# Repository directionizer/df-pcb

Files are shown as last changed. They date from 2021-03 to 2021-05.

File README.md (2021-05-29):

# df-pcb

Directionizer is a student project by Mason Ahner, Jared Beller, and John Fiorini for the spring 2021 session of ECE 2804 at Virginia Tech. The "directionizer" is a handheld device for locating a 1 kHz audio beacon. This repository contains KiCad schematics and PCBs for the directionizer hardware.

## Structure

The original design made during prototyping can be found in [schematic](schematic/). This was broken into three individual boards, which are stacked to form the final device. From bottom to top, the boards are [processing](processing/), [audio](audio/), and [display](display/). Each board's schematic and layout is in it's respective folder. For manufacturing, the three boards were combined into a panel. The final panel layout can be seen in the [panel](panel/) folder. Files sent to the board house, including gerbers, a bom, and smt placement, are in the [production](production/) folder.

## Licensing

Copyright (C) 2021  Mason Ahner, Jared Beller, and John Fiorini

This program is released under the [GNU General Public License, Version 3](https://www.gnu.org/licenses/gpl-3.0.txt) or later. See [LICENSE](LICENSE) for more information.

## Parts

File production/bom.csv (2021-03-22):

Comment | Designator | Footprint | LCSC Part No.
22pF | C1,C3,C9,C10,C15,C21,C27 | 0603 | C1653
4.7nF | C16,C18,C22,C24,C28,C30 | 0603 | C53987
10nF | C2 | 0603 | C57112
100nF | C4,C5,C6,C7,C8,C11,C12,C33,C34 | 0603 | C14663
2.2uF | C13,C17,C19,C20,C23,C25,C26,C29,C31,C32 | 3216 | C179115
10uF | C14 | 0805 | C15850
10uH | L1 | 0805 | C1046
330R | R40,R44,R48 | 0603 | C23138
390R | R37,R38,R39,R41,R42,R43,R45,R46,R47,R49,R50,R51 | 0603 | C23151
680R | R36 | 0603 | C23228
2.7k | R15,R24,R33 | 0603 | C13167
3k | R17,R26,R35 | 0603 | C4211
5.1k | R1,R2 | 0603 | C23186
5.6k | R10,R19,R28 | 0603 | C23189
8.2k | R4 | 0603 | C25981
10k | R6 | 1206 | C17902
12k | R3,R12,R21,R30 | 0603 | C22790
51k | R14,R23,R32 | 0603 | C23196
100k | R7,R8,R16,R25,R34 | 0603 | C25803
220k | R13,R22,R31 | 0603 | C22961
430k | R11,R20,R29 | 0603 | C25969
1M | R5,R9,R18,R27 | 0603 | C22935
12MHz | Y1 | 3225 | C9002
16MHz | Y2 | 3225 | C13738
Schottky | D1,D2,D3 | SOD-123 | C8598
Push Button | SW1 | SPST_SKQG | C318884
CH340G | U1 | SOIC-16 | C14267
ATmega328P-AU | U2 | TQFP-32 | C14877
LM324DT | U3,U4 | SOIC-14 | C71035
74HC238 | U5,U6 | SOIC-16 | C5620
TYPE-C-31-M-12 | J4 | TYPE-C-31_L8.94_W7.3 | C165948

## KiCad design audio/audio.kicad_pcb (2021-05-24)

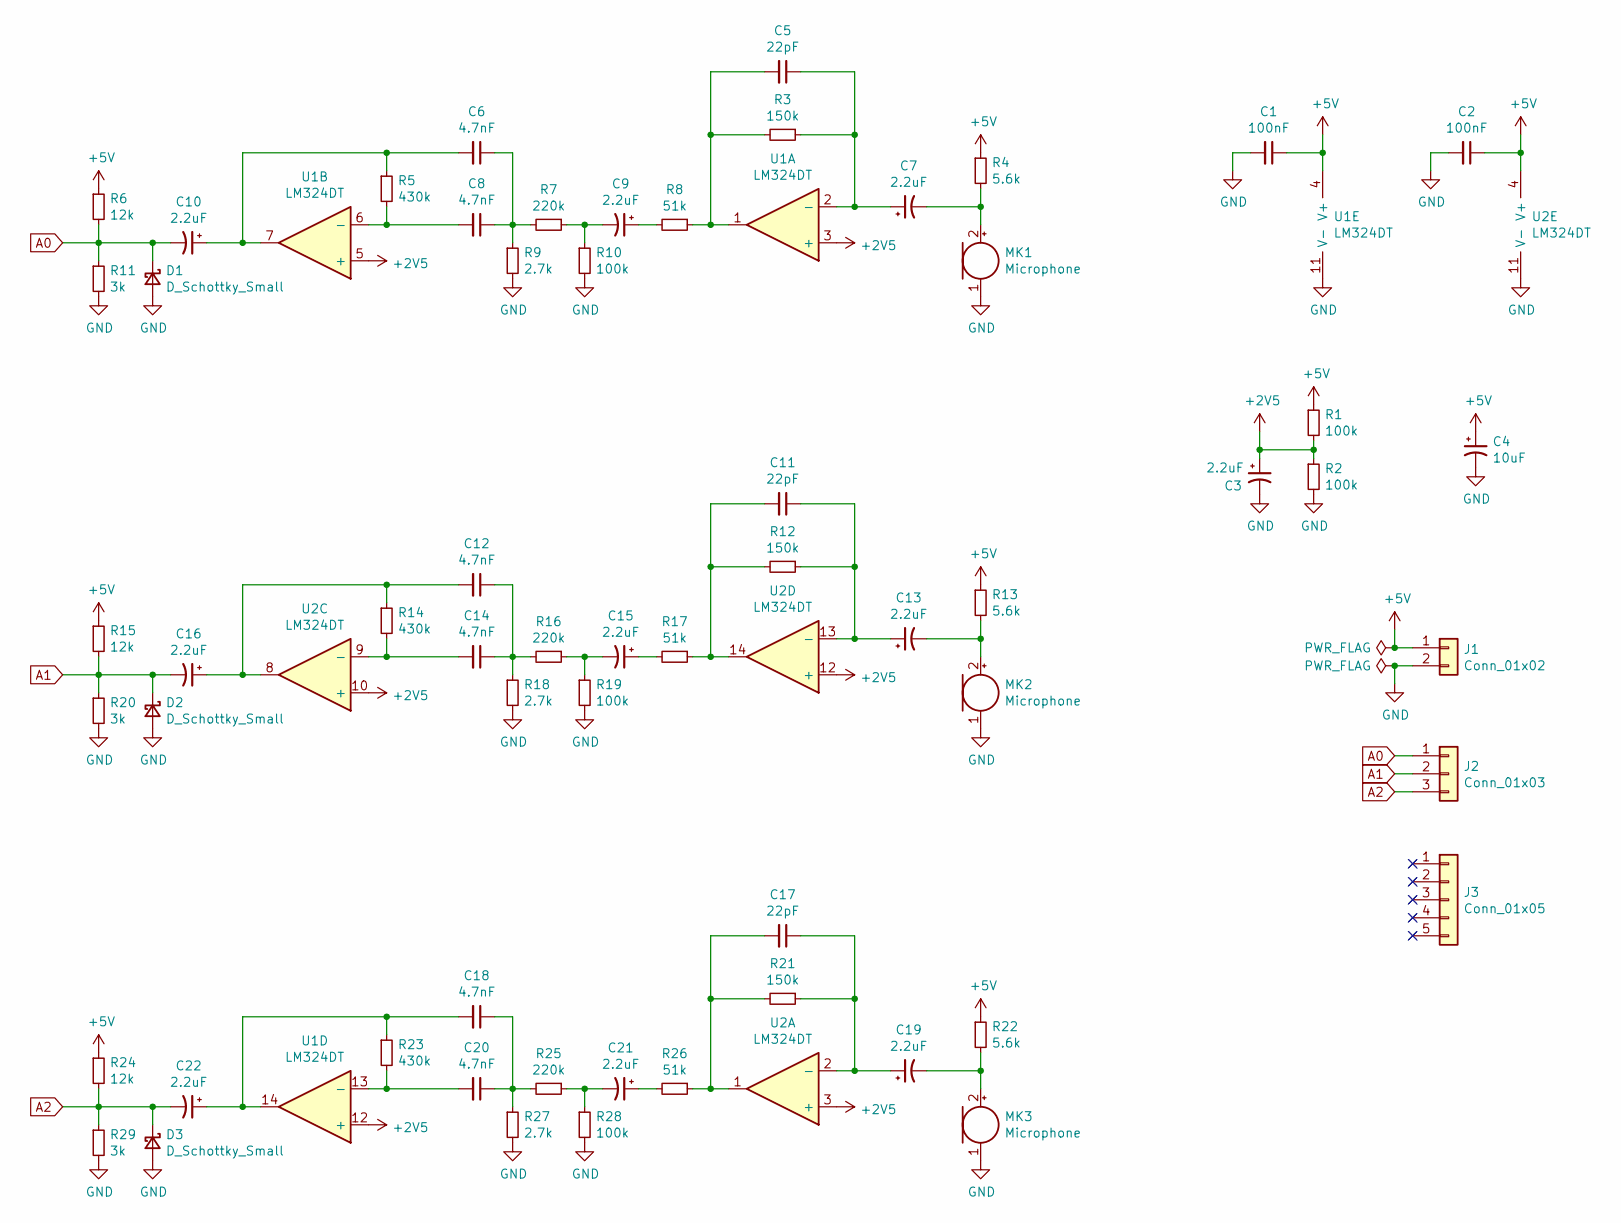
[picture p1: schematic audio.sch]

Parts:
C1, C2: 100nF; C_0603_1608Metric
C3, C7, C9, C10, C13, C15, C16, C19, C21, C22: 2.2uF; CP_EIA-3216-18_Kemet-A
C4: 10uF; CP_EIA-3216-18_Kemet-A
C5, C11, C17: 22pF; C_0603_1608Metric
C6, C8, C12, C14, C18, C20: 4.7nF; C_0603_1608Metric
D1, D2, D3: D_Schottky_Small; D_SOD-123
J1: Conn_01x02; 310-XX-102-41-001000
J2: Conn_01x03; 310-XX-103-41-001000
J3: Conn_01x05; 310-XX-105-41-001000
MK1, MK2, MK3: Microphone; CMA-6542PF
R1, R2, R10, R19, R28: 100k; R_0603_1608Metric
R3, R12, R21: 150k; R_0603_1608Metric
R4, R13, R22: 5.6k; R_0603_1608Metric
R5, R14, R23: 430k; R_0603_1608Metric
R6, R15, R24: 12k; R_0603_1608Metric
R7, R16, R25: 220k; R_0603_1608Metric
R8, R17, R26: 51k; R_0603_1608Metric
R9, R18, R27: 2.7k; R_0603_1608Metric
R11, R20, R29: 3k; R_0603_1608Metric
U1, U2: LM324DT; SOIC-14_3.9x8.7mm_P1.27mm

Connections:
+2V5: C3.1, R1.2, R2.1, U1.3 (+), U1.5 (+), U1.12 (+), U2.3 (+), U2.10 (+), U2.12 (+)
+5V: C1.1, C2.1, C4.1, J1.1, R1.1, R4.1, R6.1, R13.1, R15.1, R22.1, R24.1, U1.4 (V+), U2.4 (V+)
A0: C10.2, D1.1 (K), J2.1, R6.2, R11.1
A1: C16.2, D2.1 (K), J2.2, R15.2, R20.1
A2: C22.2, D3.1 (K), J2.3, R24.2, R29.1
GND: C1.2, C2.2, C3.2, C4.2, D1.2 (A), D2.2 (A), D3.2 (A), J1.2, MK1.1 (-), MK2.1 (-), MK3.1 (-), R2.2, R9.2, R10.2, R11.2, R18.2, R19.2, R20.2, R27.2, R28.2, R29.2, U1.11 (V-), U2.11 (V-)
unnamed: C5.1, C7.1, R3.1, U1.2 (-)
unnamed: C5.2, R3.2, R8.1, U1.1
unnamed: C6.1, C8.1, R7.2, R9.1
unnamed: C7.2, MK1.2 (+), R4.2
unnamed: C8.2, R5.2, U1.6 (-)
unnamed: C9.1, R8.2
unnamed: C9.2, R7.1, R10.1
unnamed: C6.2, C10.1, R5.1, U1.7
unnamed: C11.1, C13.1, R12.1, U2.13 (-)
unnamed: C11.2, R12.2, R17.1, U2.14
unnamed: C12.1, C14.1, R16.2, R18.1
unnamed: C12.2, C16.1, R14.1, U2.8
unnamed: C13.2, MK2.2 (+), R13.2
unnamed: C14.2, R14.2, U2.9 (-)
unnamed: C15.1, R17.2
unnamed: C15.2, R16.1, R19.1
unnamed: C17.1, C19.1, R21.1, U2.2 (-)
unnamed: C17.2, R21.2, R26.1, U2.1
unnamed: C18.1, C20.1, R25.2, R27.1
unnamed: C18.2, C22.1, R23.1, U1.14
unnamed: C19.2, MK3.2 (+), R22.2
unnamed: C20.2, R23.2, U1.13 (-)
unnamed: C21.1, R26.2
unnamed: C21.2, R25.1, R28.1

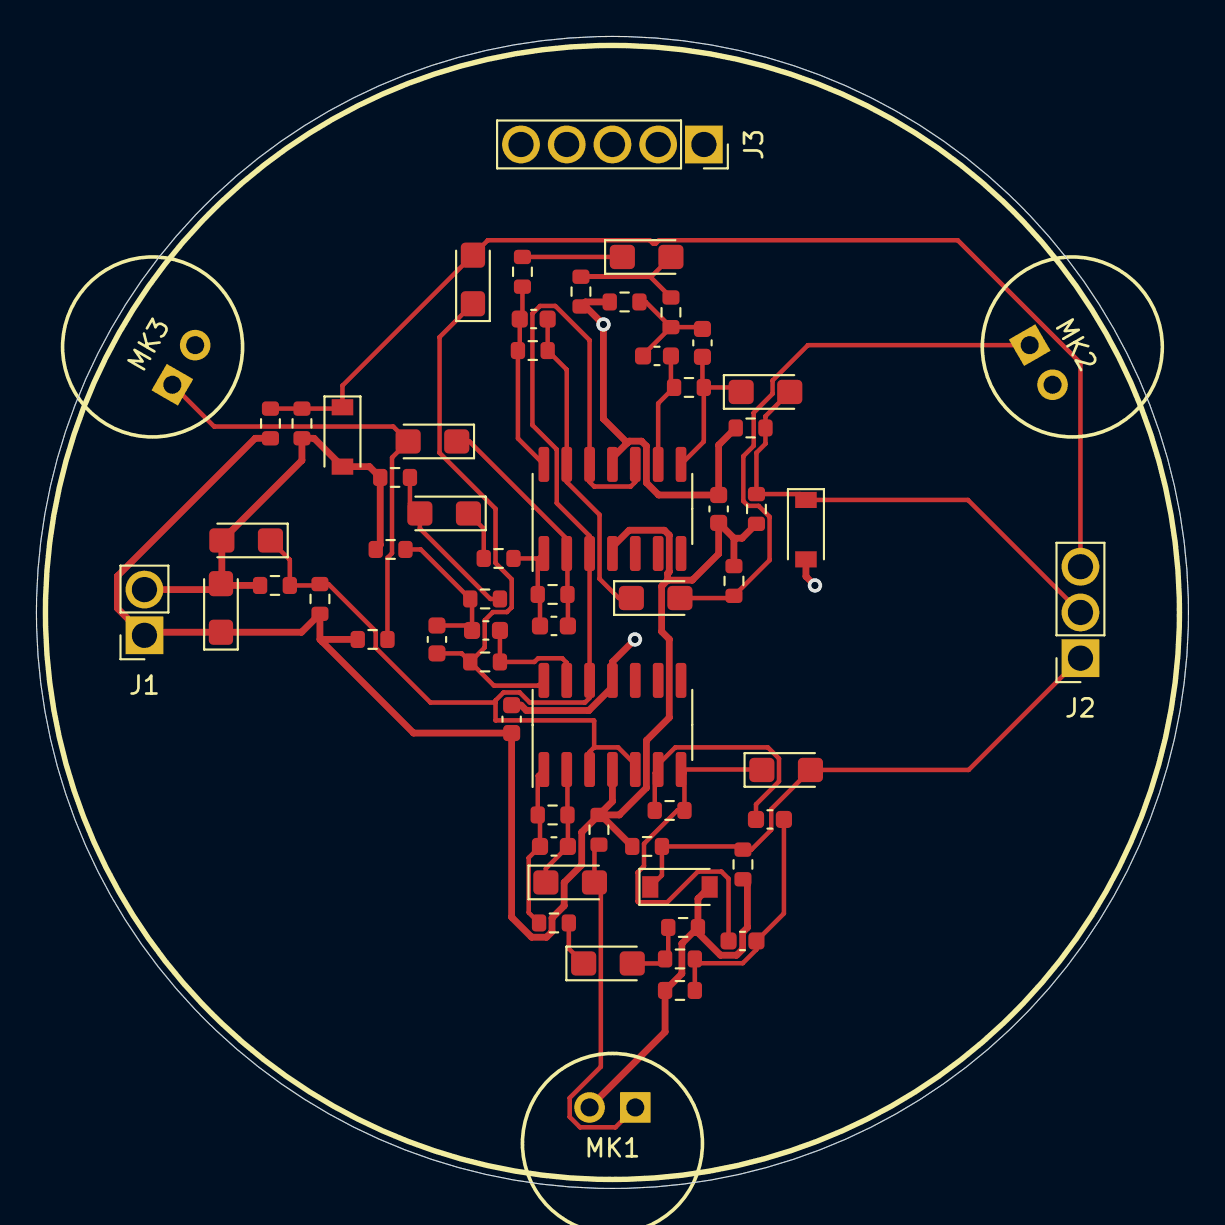
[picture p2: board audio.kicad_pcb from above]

Board: 2 copper layers, 64.0 x 64.0 mm, 62 parts (0 on the bottom side), 30 nets.

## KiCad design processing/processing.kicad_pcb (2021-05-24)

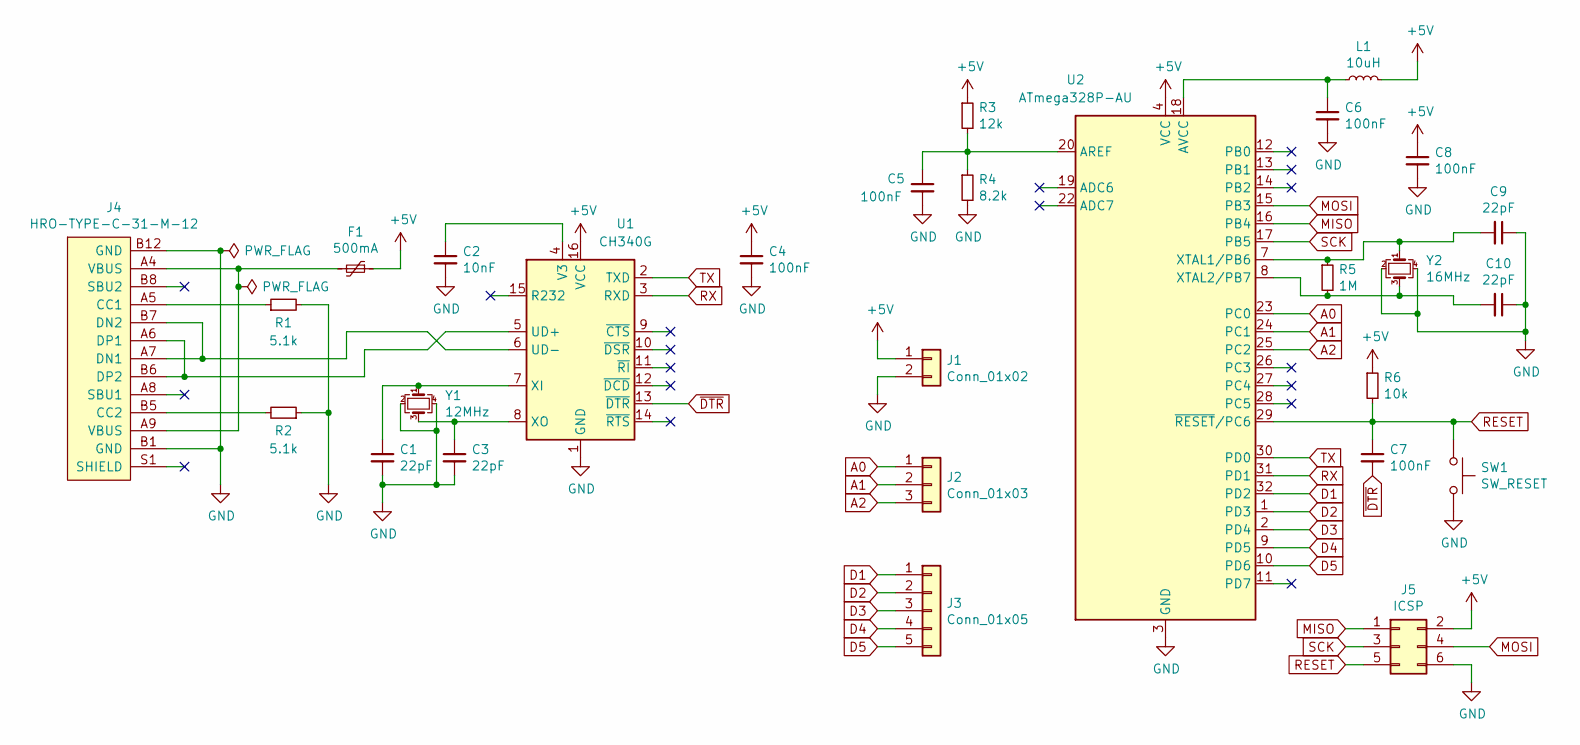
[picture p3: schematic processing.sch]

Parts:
C1, C3, C9, C10: 22pF; C_0603_1608Metric
C2: 10nF; C_0603_1608Metric
C4, C5, C6, C7, C8: 100nF; C_0603_1608Metric
F1: 500mA; Fuse_1206_3216Metric_Pad1.42x1.75mm_HandSolder
J1: Conn_01x02; 310-XX-102-41-001000
J2: Conn_01x03; 310-XX-103-41-001000
J3: Conn_01x05; 310-XX-105-41-001000
J4: HRO-TYPE-C-31-M-12; USB_C_Receptacle_HRO_TYPE-C-31-M-12
J5: ICSP; PinHeader_2x03_P2.54mm_Vertical
L1: 10uH; L_0805_2012Metric
R1, R2: 5.1k; R_0603_1608Metric
R3: 12k; R_0603_1608Metric
R4: 8.2k; R_0603_1608Metric
R5: 1M; R_0603_1608Metric
R6: 10k; R_1206_3216Metric
SW1: SW_RESET; SW_SPST_SKQG_WithoutStem
U1: CH340G; SOIC-16_3.9x9.9mm_P1.27mm
U2: ATmega328P-AU; TQFP-32_7x7mm_P0.8mm
Y1: 12MHz; Crystal_SMD_3225-4Pin_3.2x2.5mm
Y2: 16MHz; Crystal_SMD_3225-4Pin_3.2x2.5mm

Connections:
+5V: C4.1, C8.1, F1.1, J1.1, J5.2, L1.2, R3.1, R6.1, U1.16 (VCC), U2.4 (VCC), U2.6 (VCC)
A0: J2.1, U2.23 (PC0)
A1: J2.2, U2.24 (PC1)
A2: J2.3, U2.25 (PC2)
D1: J3.1, U2.32 (PD2)
D2: J3.2, U2.1 (PD3)
D3: J3.3, U2.2 (PD4)
D4: J3.4, U2.9 (PD5)
D5: J3.5, U2.10 (PD6)
GND: C1.2, C2.2, C3.2, C4.2, C5.2, C6.2, C8.2, C9.1, C10.1, J1.2, J4.B1 (GND), J4.B12 (GND), J5.6, R1.2, R2.1, R4.2, SW1.2, U1.1 (GND), U2.3 (GND), U2.5 (GND), U2.21 (GND), Y1.2, Y1.4, Y2.2, Y2.4
MISO: J5.1, U2.16 (PB4)
MOSI: J5.4, U2.15 (PB3)
unnamed: C1.1, U1.7 (XI), Y1.1
unnamed: C2.1, U1.4 (V3)
unnamed: C3.1, U1.8 (XO), Y1.3
unnamed: C5.1, R3.2, R4.1, U2.20 (AREF)
unnamed: C6.1, L1.1, U2.18 (AVCC)
unnamed: C9.2, R5.1, U2.7 (XTAL1/PB6), Y2.1
unnamed: C10.2, R5.2, U2.8 (XTAL2/PB7), Y2.3
unnamed: F1.2, J4.A4 (VBUS), J4.A9 (VBUS)
unnamed: J4.A5 (CC1), R1.1
unnamed: J4.A6 (DP1), J4.B6 (DP2), U1.5 (UD+)
unnamed: J4.A7 (DN1), J4.B7 (DN2), U1.6 (UD-)
unnamed: J4.B5 (CC2), R2.2
RESET: C7.1, J5.5, R6.2, SW1.1, U2.29 (~RESET~/PC6)
RX: U1.3 (RXD), U2.31 (PD1)
SCK: J5.3, U2.17 (PB5)
TX: U1.2 (TXD), U2.30 (PD0)
~DTR: C7.2, U1.13 (~DTR)

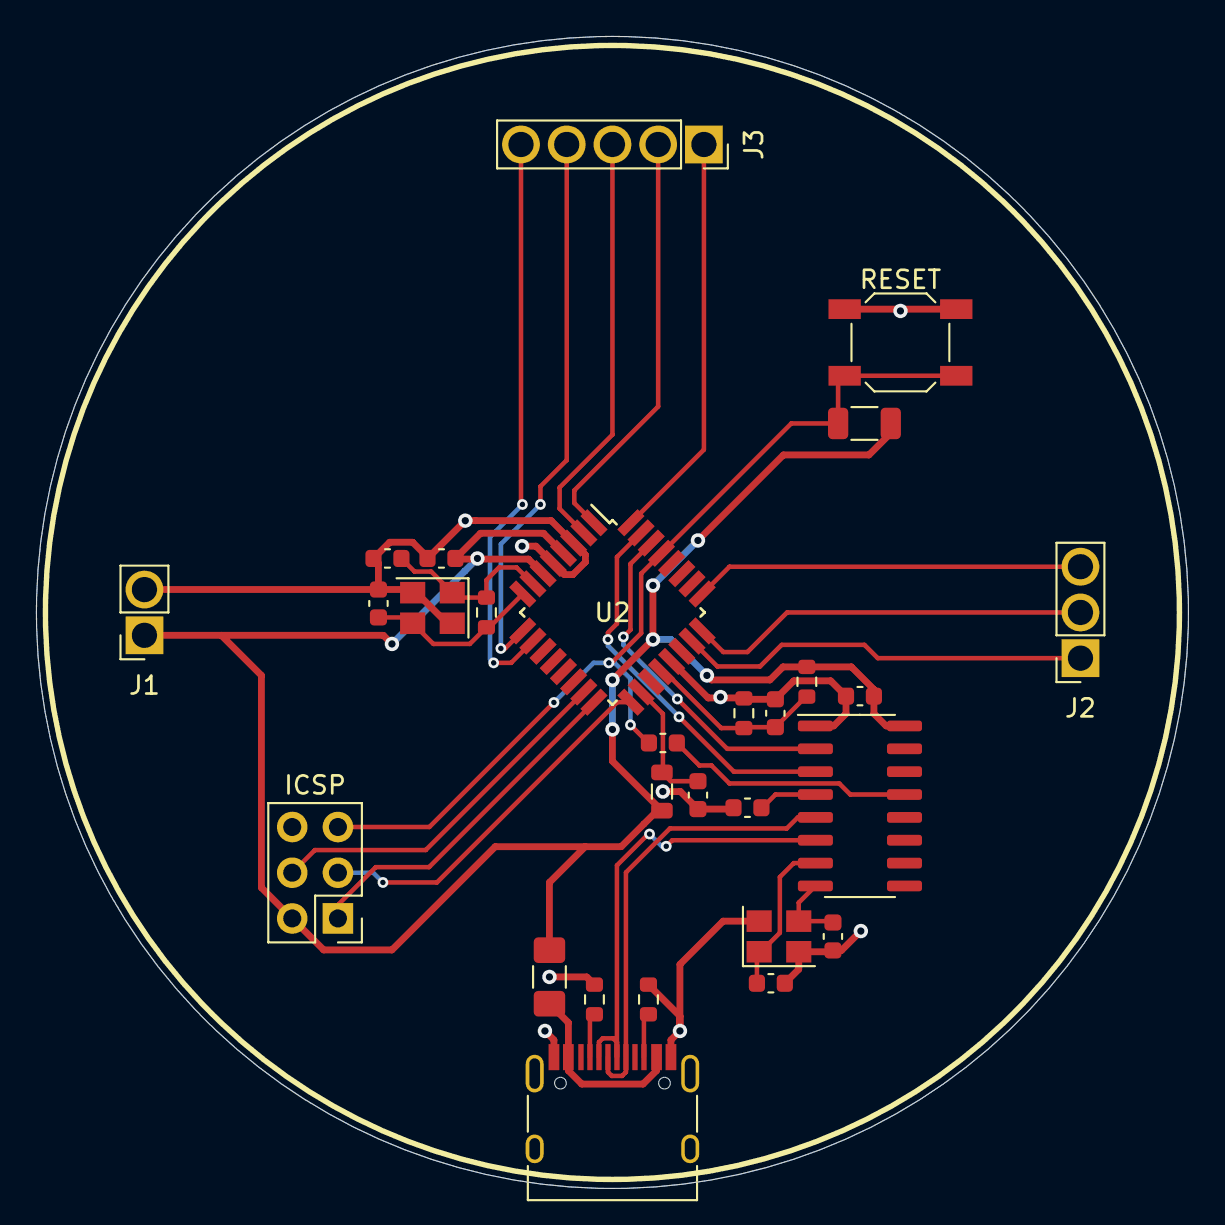
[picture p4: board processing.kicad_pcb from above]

Board: 2 copper layers, 64.0 x 64.0 mm, 28 parts (0 on the bottom side), 29 nets.

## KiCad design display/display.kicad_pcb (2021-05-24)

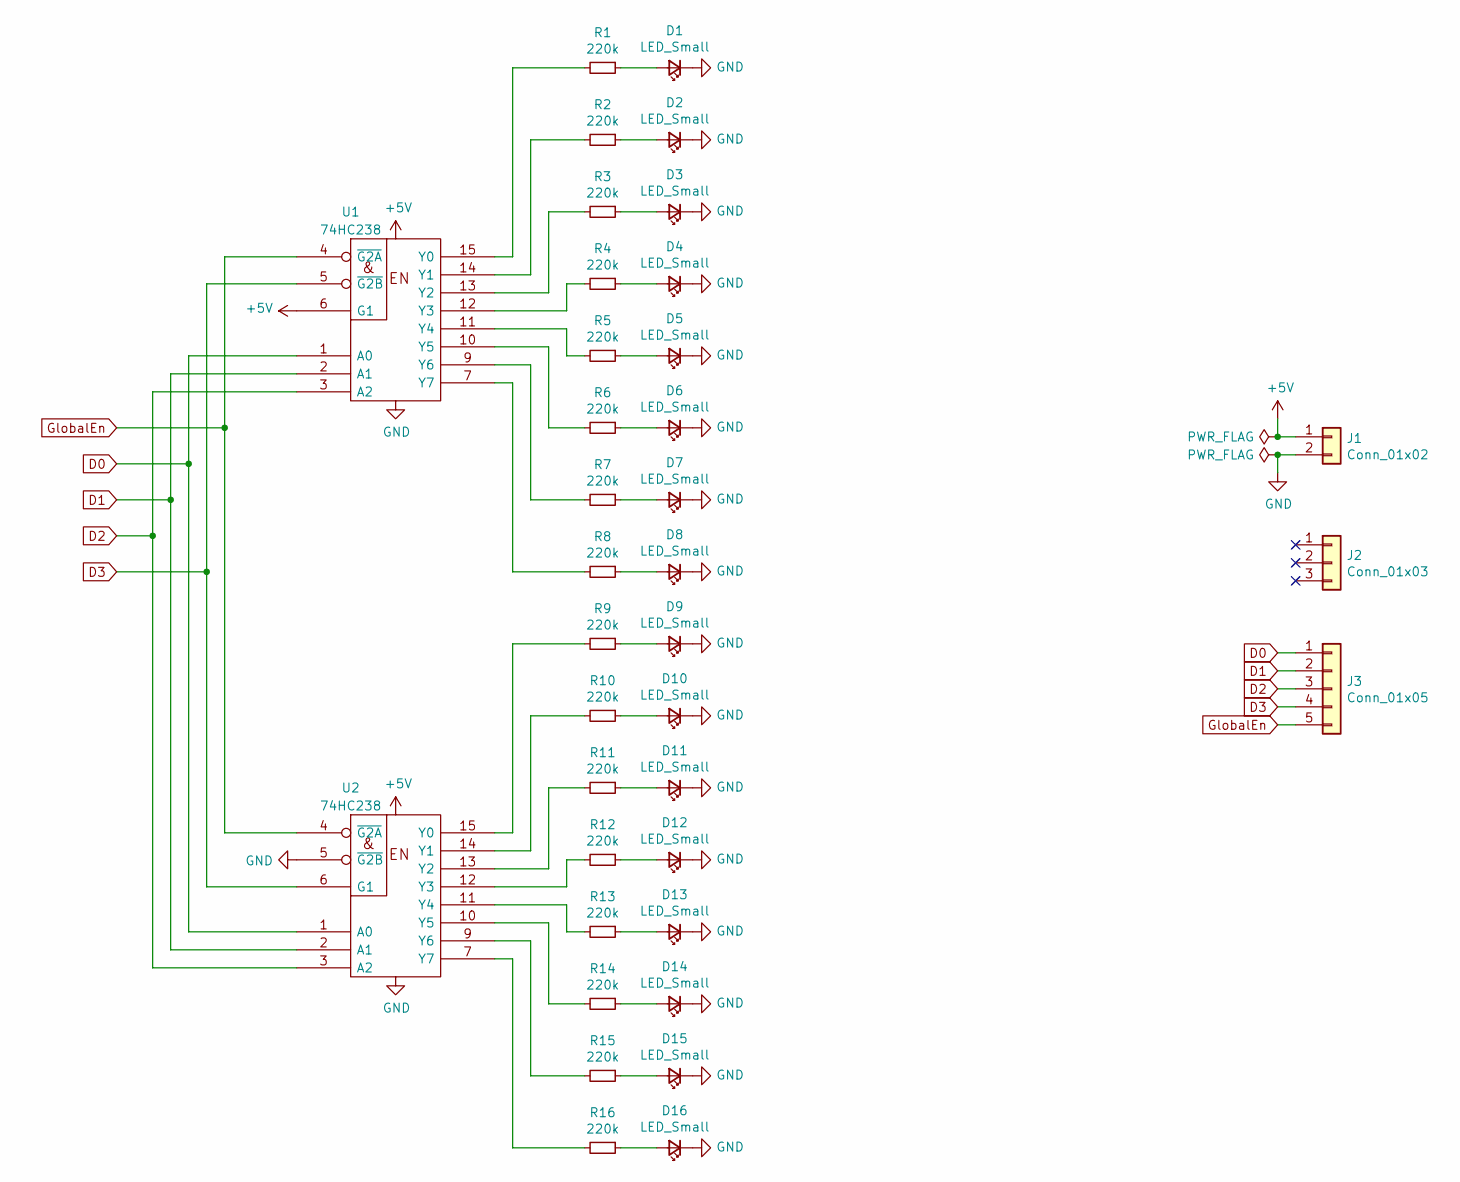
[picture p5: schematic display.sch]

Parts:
D1, D2, D3, D4, D5, D6, D7, D8, D9, D10, D11, D12, D13, D14, D15, D16: LED_Small; LED_D5.0mm
J1: Conn_01x02; 310-XX-102-41-001000
J2: Conn_01x03; 310-XX-103-41-001000
J3: Conn_01x05; 310-XX-105-41-001000
R1, R2, R3, R4, R5, R6, R7, R8, R9, R10, R11, R12, R13, R14, R15, R16: 220k; R_0603_1608Metric
U1, U2: 74HC238; SOIC-16_3.9x9.9mm_P1.27mm

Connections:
+5V: J1.1, U1.6 (G1), U1.16 (VCC), U2.16 (VCC)
D0: J3.1, U1.1 (A0), U2.1 (A0)
D1: J3.2, U1.2 (A1), U2.2 (A1)
D2: J3.3, U1.3 (A2), U2.3 (A2)
D3: J3.4, U1.5 (~G2B), U2.6 (G1)
GND: D1.1 (K), D2.1 (K), D3.1 (K), D4.1 (K), D5.1 (K), D6.1 (K), D7.1 (K), D8.1 (K), D9.1 (K), D10.1 (K), D11.1 (K), D12.1 (K), D13.1 (K), D14.1 (K), D15.1 (K), D16.1 (K), J1.2, U1.8 (GND), U2.5 (~G2B), U2.8 (GND)
GlobalEn: J3.5, U1.4 (~G2A), U2.4 (~G2A)
unnamed: D1.2 (A), R1.1
unnamed: D2.2 (A), R2.1
unnamed: D3.2 (A), R3.1
unnamed: D4.2 (A), R4.1
unnamed: D5.2 (A), R5.1
unnamed: D6.2 (A), R6.1
unnamed: D7.2 (A), R7.1
unnamed: D8.2 (A), R8.1
unnamed: D9.2 (A), R9.1
unnamed: D10.2 (A), R10.1
unnamed: D11.2 (A), R11.1
unnamed: D12.2 (A), R12.1
unnamed: D13.2 (A), R13.1
unnamed: D14.2 (A), R14.1
unnamed: D15.2 (A), R15.1
unnamed: D16.2 (A), R16.1
unnamed: R1.2, U1.15 (Y0)
unnamed: R2.2, U1.14 (Y1)
unnamed: R3.2, U1.13 (Y2)
unnamed: R4.2, U1.12 (Y3)
unnamed: R5.2, U1.11 (Y4)
unnamed: R6.2, U1.10 (Y5)
unnamed: R7.2, U1.9 (Y6)
unnamed: R8.2, U1.7 (Y7)
unnamed: R9.2, U2.15 (Y0)
unnamed: R10.2, U2.14 (Y1)
unnamed: R11.2, U2.13 (Y2)
unnamed: R12.2, U2.12 (Y3)
unnamed: R13.2, U2.11 (Y4)
unnamed: R14.2, U2.10 (Y5)
unnamed: R15.2, U2.9 (Y6)
unnamed: R16.2, U2.7 (Y7)

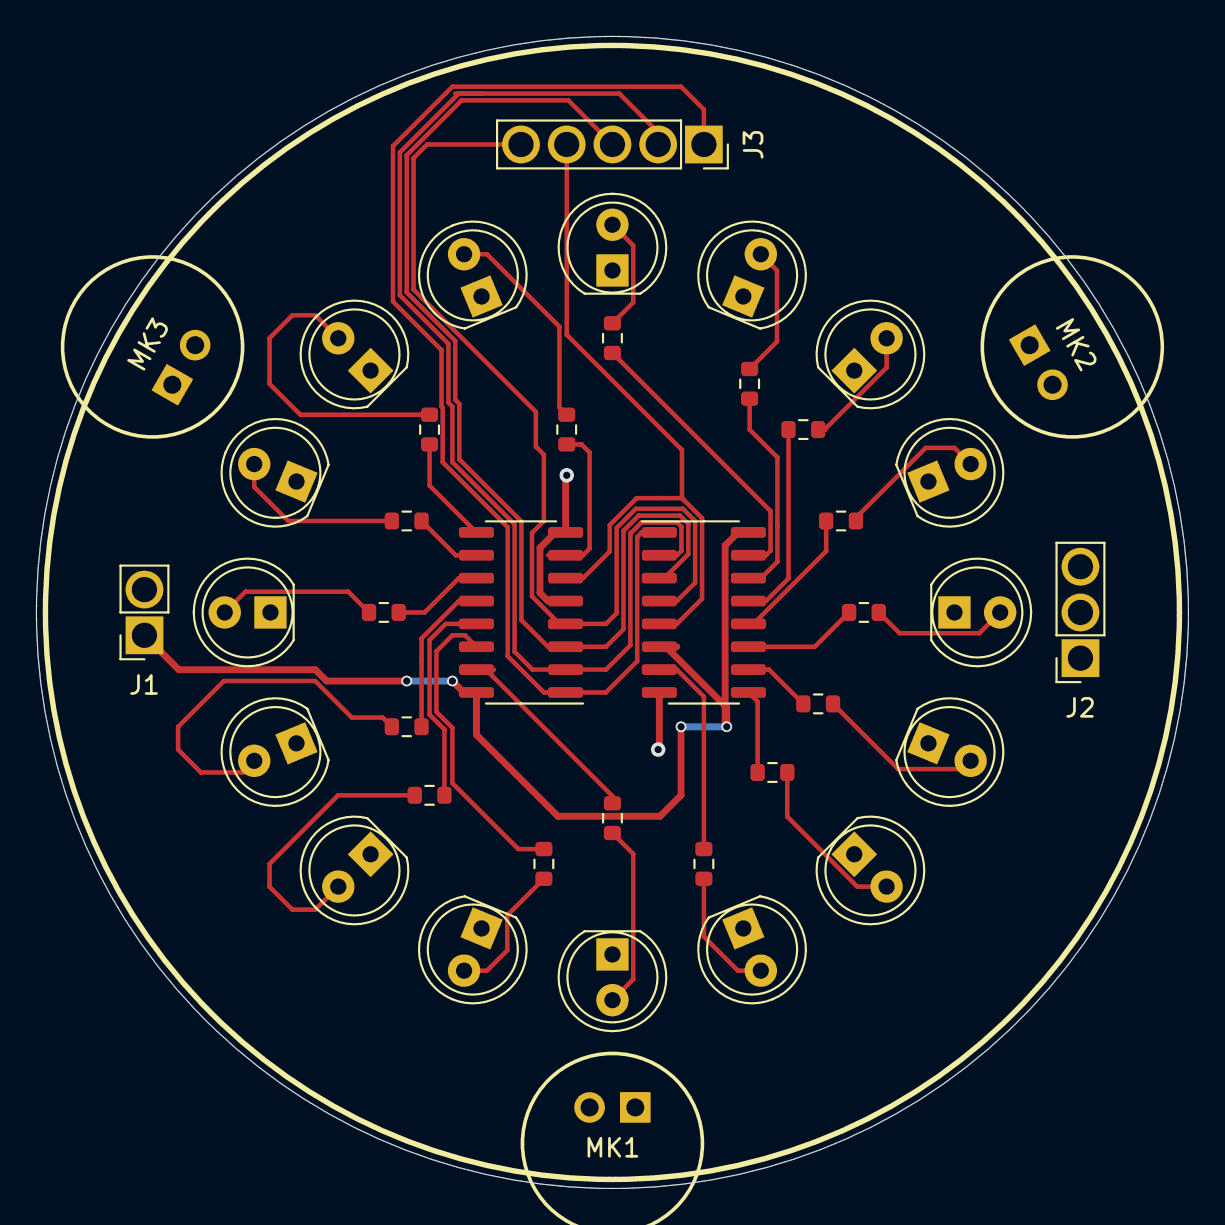
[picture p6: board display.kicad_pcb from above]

Board: 2 copper layers, 64.0 x 64.0 mm, 40 parts (0 on the bottom side), 39 nets.

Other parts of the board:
MK1, MK2, MK3: Microphone; CMA-6542PF

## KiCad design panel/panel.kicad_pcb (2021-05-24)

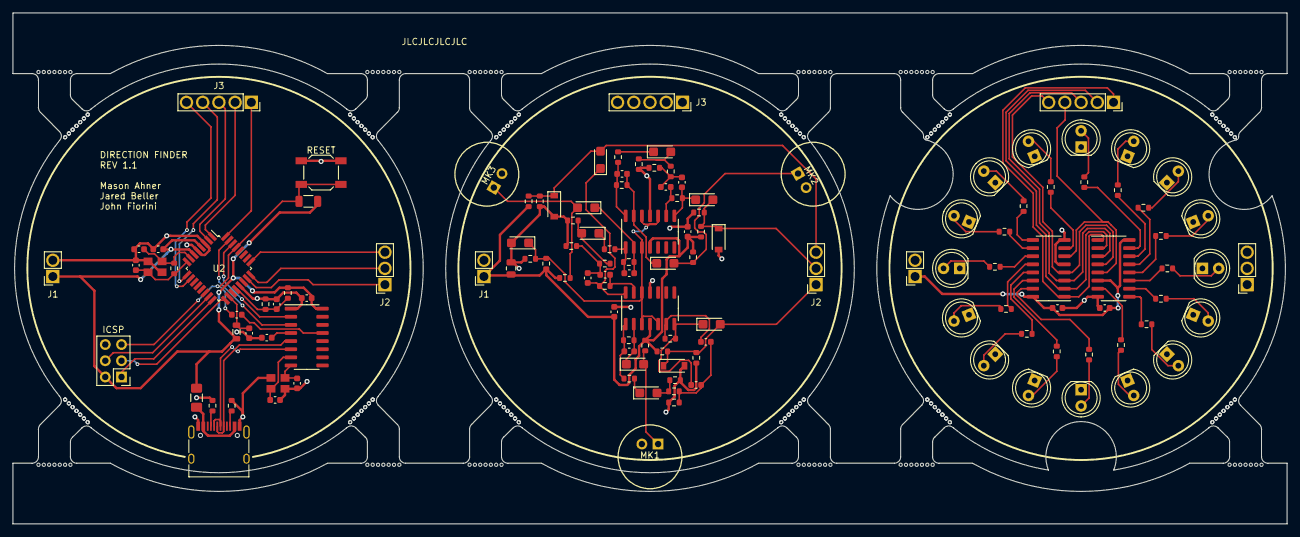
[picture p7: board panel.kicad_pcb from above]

Board: 2 copper layers, 199.5 x 80.0 mm, 129 parts (0 on the bottom side), 85 nets.

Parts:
C1, C3, C9, C10, C15, C21, C27: 22pF; C_0603_1608Metric
C2: 10nF; C_0603_1608Metric
C4, C5, C6, C7, C8, C11, C12, C33, C34: 100nF; C_0603_1608Metric
C13, C17, C19, C20, C23, C25, C26, C29, C31, C32: 2.2uF; CP_EIA-3216-18_Kemet-A
C14: 10uF; C_0805_2012Metric
C16, C18, C22, C24, C28, C30: 4.7nF; C_0603_1608Metric
D1, D2, D3: D_Schottky_Small; D_SOD-123
D1#2, D2#2, D3#2, D4, D5, D6, D7, D8, D9, D10, D11, D12, D13, D14, D15, D16: LED_Small; LED_D5.0mm
F1: 500mA; Fuse_1206_3216Metric_Pad1.42x1.75mm_HandSolder
J1, J1#2, J1#3: Conn_01x02; 310-XX-102-41-001000
J2, J2#2, J2#3: Conn_01x03; 310-XX-103-41-001000
J3, J3#2, J3#3: Conn_01x05; 310-XX-105-41-001000
J4: HRO-TYPE-C-31-M-12; USB_C_Receptacle_HRO_TYPE-C-31-M-12
J5: ICSP; PinHeader_2x03_P2.54mm_Vertical
L1: 10uH; L_0805_2012Metric
MK1, MK2, MK3: Microphone; CMA-6542PF
R1, R2: 5.1k; R_0603_1608Metric
R3, R12, R21, R30: 12k; R_0603_1608Metric
R4: 8.2k; R_0603_1608Metric
R5, R9, R18, R27: 1M; R_0603_1608Metric
R6: 10k; R_1206_3216Metric
R7, R8, R16, R25, R34: 100k; R_0603_1608Metric
R10, R19, R28: 5.6k; R_0603_1608Metric
R11, R20, R29: 430k; R_0603_1608Metric
R13, R22, R31: 220k; R_0603_1608Metric
R14, R23, R32: 51k; R_0603_1608Metric
R15, R24, R33: 2.7k; R_0603_1608Metric
R17, R26, R35: 3k; R_0603_1608Metric
R36: 680; R_0603_1608Metric
R37, R38, R39, R41, R42, R43, R45, R46, R47, R49, R50, R51: 390; R_0603_1608Metric
R40, R44, R48: 330; R_0603_1608Metric
SW1: SW_RESET; SW_SPST_SKQG_WithoutStem
U1: CH340G; SOIC-16_3.9x9.9mm_P1.27mm
U2: ATmega328P-AU; TQFP-32_7x7mm_P0.8mm
U3, U4: LM324DT; SOIC-14_3.9x8.7mm_P1.27mm
U5, U6: 74HC238; SOIC-16_3.9x9.9mm_P1.27mm
Y1: 12MHz; Crystal_SMD_3225-4Pin_3.2x2.5mm
Y2: 16MHz; Crystal_SMD_3225-4Pin_3.2x2.5mm

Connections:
+2V5: C13.1, R7.2, R8.1, U3.3, U3.5, U3.12, U4.3, U4.10, U4.12
+5V: C4.1, C8.1, C11.1, C12.1, C14.1, C33.1, C34.1, F1.1, J1.1, J1#2.1, J1#3.1, J5.2, L1.2, R3.1, R6.1, R7.1, R10.1, R12.1, R19.1, R21.1, R28.1, R30.1, U1.16, U2.4, U2.6, U3.4, U4.4, U5.6, U5.16, U6.16
A0: C20.2, D1.1, J2#2.1, J2#3.1, R12.2, R17.1, U2.23
A1: C26.2, D2.1, J2#2.2, J2#3.2, R21.2, R26.1, U2.24
A2: C32.2, D3.1, J2#2.3, J2#3.3, R30.2, R35.1, U2.25
D0: J3.1, U5.1, U6.1
D1: J3.2, J3#3.1, U2.32, U5.2, U6.2
D2: J3.3, J3#3.2, U2.1, U5.3, U6.3
D3: J3.4, J3#3.3, U2.2, U5.5, U6.6
D4: J3#3.4, U2.9
D5: J3#3.5, U2.10
GND: C1.2, C2.2, C3.2, C4.2, C5.2, C6.2, C8.2, C9.1, C10.1, C11.2, C12.2, C13.2, C14.2, C33.2, C34.2, D1.2, D1#2.1, D2.2, D2#2.1, D3.2, D3#2.1, D4.1, D5.1, D6.1, D7.1, D8.1, D9.1, D10.1, D11.1, D12.1, D13.1, D14.1, D15.1, D16.1, J1.2, J1#2.2, J1#3.2, J4.B1, J4.B12, J5.6, MK1.1, MK2.1, MK3.1, R1.2, R2.1, R4.2, R8.2, R15.2, R16.2, R17.2, R24.2, R25.2, R26.2, R33.2, R34.2, R35.2, SW1.2, U1.1, U2.3, U2.5, U2.21, U3.11, U4.11, U5.8, U6.5, U6.8, Y1.2, Y1.4, Y2.2, Y2.4
GlobalEn: J3.5, U5.4, U6.4
MISO: J5.1, U2.16
MOSI: J5.4, U2.15
unnamed: C1.1, U1.7, Y1.1
unnamed: C2.1, U1.4
unnamed: C3.1, U1.8, Y1.3
unnamed: C5.1, C15.1, C17.1, R3.2, R4.1, R9.1, U2.20, U3.2
unnamed: C15.2, R9.2, R14.1, U3.1
unnamed: C6.1, C16.1, C18.1, L1.1, R13.2, R15.1, U2.18
unnamed: C17.2, MK1.2, R10.2
unnamed: C18.2, R11.2, U3.6
unnamed: C19.1, R14.2
unnamed: C9.2, C19.2, R5.1, R13.1, R16.1, U2.7, Y2.1
unnamed: C16.2, C20.1, R11.1, U3.7
unnamed: C10.2, R5.2, U2.8, Y2.3
unnamed: C21.1, C23.1, R18.1, U4.13
unnamed: C21.2, R18.2, R23.1, U4.14
unnamed: C22.1, C24.1, R22.2, R24.1
unnamed: C22.2, C26.1, R20.1, U4.8
unnamed: C23.2, MK2.2, R19.2
unnamed: C24.2, R20.2, U4.9
unnamed: C25.1, R23.2
unnamed: C25.2, R22.1, R25.1
unnamed: C27.1, C29.1, R27.1, U4.2
unnamed: C27.2, R27.2, R32.1, U4.1
unnamed: C28.1, C30.1, R31.2, R33.1
unnamed: C28.2, C32.1, R29.1, U3.14
unnamed: C29.2, MK3.2, R28.2
unnamed: C30.2, R29.2, U3.13
unnamed: C31.1, R32.2
unnamed: C31.2, R31.1, R34.1
unnamed: D1#2.2, R36.1
unnamed: D2#2.2, R37.1
unnamed: D3#2.2, R38.1
unnamed: D4.2, R39.1
unnamed: D5.2, R40.1
unnamed: D6.2, R41.1
unnamed: D7.2, R42.1
unnamed: D8.2, R43.1
unnamed: D9.2, R44.1
unnamed: D10.2, R45.1
unnamed: D11.2, R46.1
unnamed: D12.2, R47.1
unnamed: D13.2, R48.1
unnamed: D14.2, R49.1
unnamed: D15.2, R50.1
unnamed: D16.2, R51.1
unnamed: F1.2, J4.A4, J4.A9
unnamed: J4.A5, R1.1
unnamed: J4.A6, J4.B6, U1.5
unnamed: J4.A7, J4.B7, U1.6
unnamed: J4.B5, R2.2
unnamed: R36.2, U5.15
unnamed: R37.2, U5.14
unnamed: R38.2, U5.13
unnamed: R39.2, U5.12
unnamed: R40.2, U5.11
unnamed: R41.2, U5.10
unnamed: R42.2, U5.9
unnamed: R43.2, U5.7
unnamed: R44.2, U6.15
unnamed: R45.2, U6.14
unnamed: R46.2, U6.13
unnamed: R47.2, U6.12
unnamed: R48.2, U6.11
unnamed: R49.2, U6.10
unnamed: R50.2, U6.9
unnamed: R51.2, U6.7
RESET: C7.1, J5.5, R6.2, SW1.1, U2.29
RX: U1.3, U2.31
SCK: J5.3, U2.17
TX: U1.2, U2.30
~DTR: C7.2, U1.13

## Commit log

2021-02-23 initial schematic stuff
    [schematic.sch]
2021-03-09 update main schematic
    [schematic.sch]
2021-03-10 initial processing board
    [processing.kicad_pcb, processing.sch, schematic.sch]
2021-03-13 audio system approved
    [schematic.sch]
2021-03-14 base audio board
    [audio.kicad_pcb, audio.sch, processing.kicad_pcb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]
2021-03-14 properly orient pcb
    [audio.kicad_pcb, audio.sch]
2021-03-15 finish the processing board
    [processing.kicad_pcb, processing.sch]
2021-03-16 kind of messed with the "rats nest"
    [audio.kicad_pcb]
2021-03-16 routing wires
    [audio.kicad_pcb]
2021-03-16 added display pcb schematic
    [display.kicad_pcb, display.sch]
2021-03-17 2nd mic added
    [audio.kicad_pcb]
2021-03-18 fix design rules
    [audio.kicad_pcb, processing.kicad_pcb]
2021-03-18 display board template
    [display.kicad_pcb, display.sch]
2021-03-18 resize boards
    [audio.kicad_pcb, display.kicad_pcb, processing.kicad_pcb]
2021-03-19 Finished adding audio pcb tracks
    [audio.kicad_pcb]
2021-03-20 display pcb wired
    [display.kicad_pcb]
2021-03-22 panelized and ready for manufacturing
    [bom.csv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]
2021-04-04 errata 1: rx and tx are flipped
    [panel.kicad_pcb, processing.kicad_pcb, processing.sch]
2021-05-24 errata 2: fix footprints
    [audio.kicad_pcb, audio.sch, display.kicad_pcb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]
2021-05-29 prepare for release
    [panel-B_Cu.gbr, panel-B_Mask.gbr, panel-B_SilkS.gbr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]
